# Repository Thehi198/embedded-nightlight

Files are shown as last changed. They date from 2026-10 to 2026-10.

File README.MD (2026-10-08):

# Nightlight: Event-Driven Ambient Light Controller on STM32F446RE

**Demo video:** [docs/demo.mp4](docs/demo.mp4) 

## Overview

This nightlight measures room darkness with a photoresistor and fades in red, yellow, and green LEDs in three stages as the room gets darker. It is fully event-driven on an STM32F446RE. A single interrupt callback converts each sampling window to photoresistor resistance, maps it to a normalized darkness value, and updates three 16-bit PWM channels, while the main loop sleeps on `__WFI()`. A DAC self-test verifies the ADC signal path using on board traces.

**Demo video:** [docs/demo.mp4](docs/demo.mp4) 

## Circuit

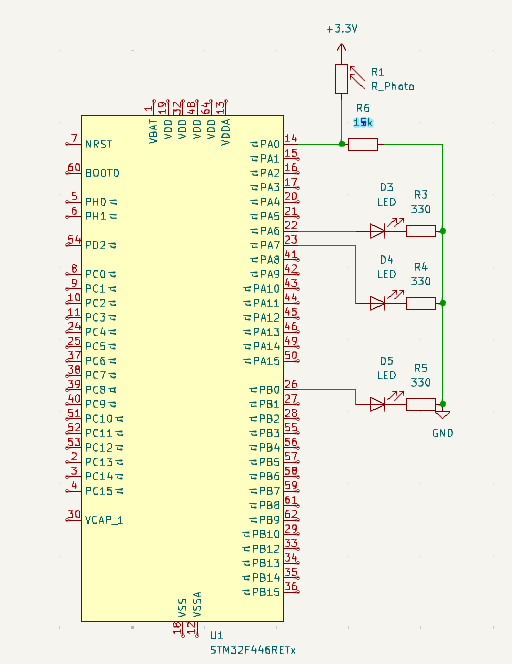
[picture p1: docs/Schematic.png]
Schematic


### Components

| Ref | Part | Value |
|:-|:-|:-|
| LDR1 | Photoresistor | Characterized below |
| R1 | Divider resistor | 15 kΩ |
| R2, R3, R4 | LED series resistors | 330 Ω |
| LED1 | Stage 1 LED | Red |
| LED2 | Stage 2 LED | Yellow |
| LED3 | Stage 3 LED | Green |

### Pin map

| Signal | MCU pin | Nucleo header | Function |
|:-|:-|:-|:-|
| Sensor | PA0 | A0 (CN8) | ADC1_IN0 |
| Self-test loopback | PA4 | A2 (CN8), unconnected | DAC_OUT1 / ADC1_IN4 |
| LED stage 1 | PA6 | D12 (CN5) | TIM3_CH1, AF2 |
| LED stage 2 | PA7 | D11 (CN5) | TIM3_CH2, AF2 |
| LED stage 3 | PB0 | A3 (CN8) | TIM3_CH3, AF2 |
| Sensor supply | 3V3 | CN6 | |
| Ground | GND | CN6 | |

### Divider design

ADC value rises with light.

$$c = 4096 \cdot \frac{R_{DIV}}{R_{LDR} + R_{DIV}}$$

For maximum voltage swing across the operating range, $R_{DIV} \approx \sqrt{R_{bright} R_{dark}}$.

## Sensor Characterization

### Method
LDR resistance was measured with a multimeter under different light sources of increasing brightness. 

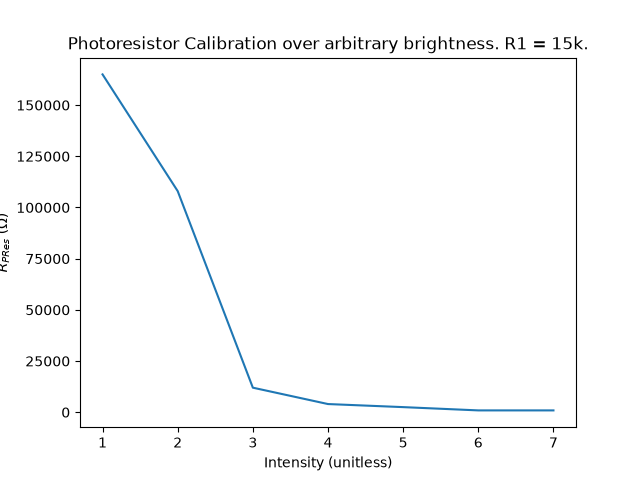
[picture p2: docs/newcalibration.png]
Resistance vs. intensity


The relationship is not linear. On log-log axes the data falls on a straight line, so the photoresistor follows a power law:

$$R = A \cdot L^{-\gamma}$$

Because $\ln R$ is linear in $\ln L$, and light intensity is roughly logarithmic, only the two calibration endpoints, max and min are needed

## System Architecture

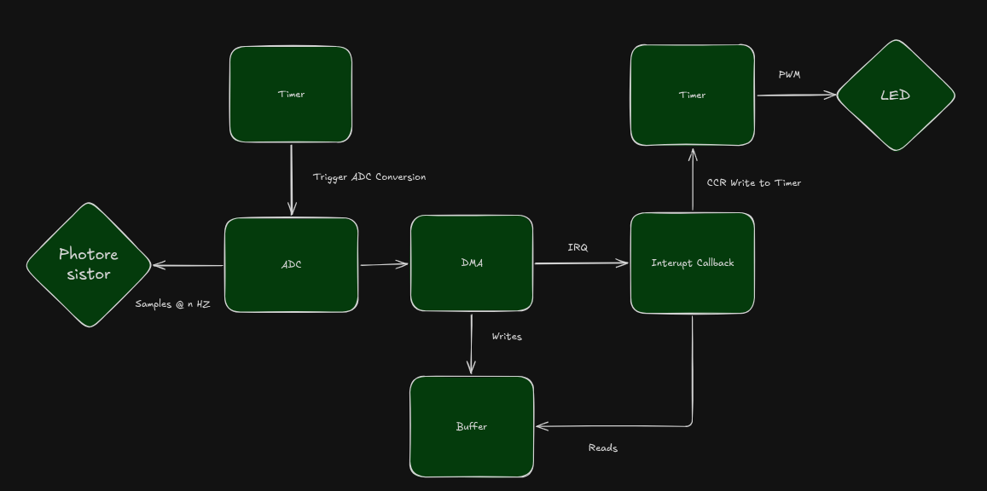
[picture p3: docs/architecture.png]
Architecture diagram


### Data flow

1. **TIM2** counts at 1 MHz effective and overflows every 833 µs. Each update event drives TRGO, which starts one ADC conversion in hardware.
2. **ADC1** converts PA0 with a 480-cycle sample time .
3. **DMA2 Stream 0** copies each result into a 120-entry circular buffer. 
4. When either half of the buffer fills, the DMA raises an interrupt and HAL calls the half-complete or complete callback.
5. **The callback** averages 60 samples, converts to resistance, maps to darkness, splits into three stages, and writes TIM3 CCR1 to CCR3.
6. **TIM3** generates three PWM waveforms continuously. 

### Brightness mapping

Average ADC sample output is converted to resistance:

$$R = R_{DIV}\ \frac{4096 - c}{c}$$

The resistance is converted to a "darkness" value to be normalized and processed by the stage function

$$d = \frac{\ln R - \ln R_{bright}}{\ln R_{dark} - \ln R_{bright}}$$

This value was clamped betwene 0 and 1

Darkness is converted to stage to stage $k = 0, 1, 2$:

$$s_k = (3d - k,\ 0,\ 1), \qquad \text{CCR}_{k+1} = 65535 \cdot s_k$$

Calibration: $R_{bright}$ = 2000 Ω, $R_{dark}$ = 8000 Ω.

## Design Decisions

| Constant | Value | Rationale |
|:-|:-|:-|
| System clock | 180 MHz from internal HSI | Maximum rated speed |
| ADC clock | 22.5 MHz  | Fastest sample setting |
| Sampling rate | 1200 Hz | 60 samples per 50 ms |
| ADC sample time | 480 cycles | Arbitrary |
| Buffer | 120 samples, two halves | 20 Hz update rate. CPU reads the half DMA, other half is being written to.|
| PWM frequency | 1373 Hz | Arbitrary |
| Filtering | 60-sample average only | Average sample reduces jitter in PWM|
| LED color order | Red, Yellow, Green | Based on what humans best see in different levels of light |

## Register Trace

Each CubeMX setting and the register field it writes. HAL source was used to find the fields

### ADC1

ADC1 converts the sensor on PA0 once per TIM2 trigger.

| CubeMX setting | Value | Register.field = value |
|:-|:-|:-|
| Clock Prescaler | PCLK2 / 4 | ADC_CCR.ADCPRE = 01 |
| Resolution | 12 bit | ADC_CR1.RES = 00 |
| Scan Conversion | Disabled | ADC_CR1.SCAN = 0 |
| Continuous Conversion | Disabled | ADC_CR2.CONT = 0 |
| Data Alignment | Right | ADC_CR2.ALIGN = 0 |
| DMA Continuous Requests | Enabled | ADC_CR2.DDS = 1 |
| DMA enable | (at start) | ADC_CR2.DMA = 1 |
| EOC Selection | Single conversion | ADC_CR2.EOCS = 1 |
| External Trigger | TIM2 TRGO | ADC_CR2.EXTSEL = 0110 |
| Trigger Edge | Rising | ADC_CR2.EXTEN = 01 |
| Number of Conversions | 1 | ADC_SQR1.L = 0000 |
| Rank 1 Channel | 0 | ADC_SQR3.SQ1 = 0 |
| Rank 1 Sample Time | 480 cycles | ADC_SMPR2.SMP0 = 111 |
| Self-test channel | 4 (flag only) | ADC_SQR3.SQ1 = 4, ADC_SMPR2.SMP4 = 111 |

### DMA2 Stream 0

DMA2 Stream 0 moves every ADC result into a 120-sample circular buffer and interrupts at each half.

| CubeMX setting | Value | Register.field = value |
|:-|:-|:-|
| Request | ADC1 | DMA_S0CR.CHSEL = 000 |
| Direction | Peripheral to memory | DMA_S0CR.DIR = 00 |
| Mode | Circular | DMA_S0CR.CIRC = 1 |
| Memory increment | On | DMA_S0CR.MINC = 1 |
| Peripheral increment | Off | DMA_S0CR.PINC = 0 |
| Data width | Half word | DMA_S0CR.PSIZE = 01, MSIZE = 01 |
| Priority | High | DMA_S0CR.PL = 10 |
| FIFO | Off | DMA_S0FCR.DMDIS = 0 |
| Length | 120 (at start) | DMA_S0NDTR = 120 |

### TIM2 (ADC trigger)

TIM2 paces the ADC at 1.2 kHz:

| CubeMX setting | Value | Register.field = value |
|:-|:-|:-|
| Prescaler | 74 | TIM2_PSC = 74 |
| Counter Period | 999 | TIM2_ARR = 999 |
| Counter Mode | Up | TIM2_CR1.DIR = 0 |
| Auto-reload preload | Enable | TIM2_CR1.ARPE = 1 |
| Trigger Event (TRGO) | Update | TIM2_CR2.MMS = 010 |

### TIM3 (LED PWM)

TIM3 drives the three LEDs with 1373 Hz, 16-bit PWM.

| CubeMX setting | Value | Register.field = value |
|:-|:-|:-|
| Prescaler | 0 | TIM3_PSC = 0 |
| Counter Period | 65535 | TIM3_ARR = 0xFFFF |
| Auto-reload preload | Enable | TIM3_CR1.ARPE = 1 |
| PWM Mode | PWM mode 1 | TIM3_CCMR1.OC1M/OC2M = 110, TIM3_CCMR2.OC3M = 110 |
| Output compare preload | Enable | OC1PE/OC2PE/OC3PE = 1 |
| Polarity | High | TIM3_CCER.CCxP = 0 |
| Output enable | (at start) | TIM3_CCER.CCxE = 1 |
| Pins | AF2 | GPIOA_AFRL.AFRL6/7 = 0010, GPIOB_AFRL.AFRL0 = 0010 |

### DAC (self-test)

The DAC drives known voltages onto PA4 for the loopback self-test and is only used when `ENABLE_DAC_SELFTEST` is 1.

| CubeMX setting | Value | Register.field = value |
|:-|:-|:-|
| Output buffer | Enable | DAC_CR.BOFF1 = 0 |
| Trigger | None | DAC_CR.TEN1 = 0 |
| Enable | (at start) | DAC_CR.EN1 = 1 |
| Data | per step | DAC_DHR12R1 |

## Testing

### DAC self-test

With `ENABLE_DAC_SELFTEST = 1`, ADC1 reads channel 4 (PA4). Each DMA callback averages 60 samples of the code written by the previous callback, compares, and writes the next code. Because the DAC and ADC share VREF+, the expected ADC code equals the DAC code.

 With the output buffer enabled, the DAC only swings from 0.2 V to $V_{DDA} - 0.2$ V (datasheet Table 85), about codes 248 to 3848, so codes near the rails are excluded.

**Tolerance.**:

| Source | Spec | LSB |
|:-|:-|:-|
| DAC offset | ±10 mV (Table 85) | ±12.4 |
| DAC gain | ±0.5% (Table 85) | ±0.005 × code |
| DAC INL | ±4 LSB (Table 85) | ±4 |
| ADC total unadjusted error | ±5 LSB (Table 76) | ±5 |

$$\text{tol}(n) = \lceil 21.4 + 0.005\,n \rceil\ \text{LSB}$$

**Results.**

| DAC code | ADC measured | Error (LSB) | Tolerance (LSB) | Pass |
|:-|:-|:-|:-|:-|
| 300 | 281 | -19 | 23 | ✓ |
| 750 | 738 | -12 | 26 | ✓ |
| 1200 | 1194 | -6 | 28 | ✓ |
| 1650 | 1654 | 4 | 30 | ✓ |
| 2100 | 2111 | 11 | 32 | ✓ |
| 2550 | 2568 | 18 | 35 | ✓ |
| 3000 | 3024 | 24 | 37 | ✓ |
| 3450 | 3479 | 29 | 39 | ✓ |
| 3800 | 3835 | 35 | 41 | ✓ |

## Obstacles

The first run of the DAC  self-test failed. The DAC stepped from 300 to 3800, but the ADC read about 1699 counts for all nine steps. Since the reading did not  not move at all while the input sweeps the full range it meant that the the ADC was not looking at the DAC. 1699 counts corresponds to about 21 kΩ on the 15 kΩ divider, a normal room-light value for the photoresistor, so the ADC was most likely still sampling PA0 instead of PA4. Covering the sensor shifted the "measured" values, which confirmed it. In the STM32CubeIDE SFR view, ADC1_SQR3.SQ1 read 0 instead of 4.

The code that switches rank 1 to channel 4 was in `USER CODE BEGIN ADC1_Init 1`. That block runs before `HAL_ADC_Init` and before CubeMX's generated channel 0 configuration, so the generated code silently overwrote my setting every boot. 

In a CubeMX project, which USER CODE block a line goes in decides when it runs relative to the generated initialization. The source looked correct; only reading the register showed what the hardware was actually configured to do.

## Build and Run

1. Open the project in STM32CubeIDE.
2. In `main.c`, set `ENABLE_DAC_SELFTEST` to `0` for normal operation or `1` for the self-test.
3. Set `R_BRIGHT_OHMS` and `R_DARK_OHMS` to your calibration values.
4. Build and flash. With the self-test enabled, inspect `st_results` and `st_pass` in Live Expressions.

## Repository Structure

```
.
├── Core/              CubeMX-generated sources; application code in main.c USER CODE blocks
├── Drivers/           HAL and CMSIS
├── docs/              Photos, schematic, plots, architecture diagram, demo video
├── characterization/  TODO: raw data and plotting script
├── nightlight.ioc     CubeMX configuration
└── README.md
```

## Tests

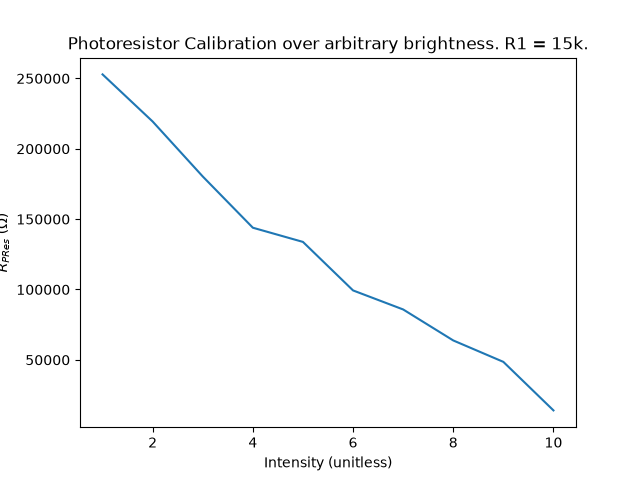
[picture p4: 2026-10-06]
calibration/newcalibration.png

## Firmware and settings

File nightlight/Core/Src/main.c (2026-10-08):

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
/* Includes ------------------------------------------------------------------*/
#include "main.h"

/* USER CODE BEGIN Includes */
#include <math.h>
/* USER CODE END Includes */

/* USER CODE BEGIN PD */
#define ADC_BUFFER_LEN   120U
#define HALF_LEN      (ADC_BUFFER_LEN / 2U)
#define R_DIV_OHMS    15000.0f
#define R_BRIGHT_OHMS   2000.0f
#define R_DARK_OHMS     80000.0f
#define PWM_MAX         65535.0f
#define ENABLE_DAC_SELFTEST  1
#define ST_N                 9U
/* USER CODE END PD */

ADC_HandleTypeDef hadc1;
DMA_HandleTypeDef hdma_adc1;

DAC_HandleTypeDef hdac;

TIM_HandleTypeDef htim2;
TIM_HandleTypeDef htim3;

/* USER CODE BEGIN PV */
static uint16_t adc_buffer[ADC_BUFFER_LEN];
volatile uint16_t adc_avg     = 0;
volatile float    pr_ohms    = 0.0f;
volatile uint32_t adc_updates = 0;
static float ln_r_bright;
static float ln_r_span;
volatile float darkness = 0.0f;



#if ENABLE_DAC_SELFTEST
typedef struct {
    uint16_t code;
    uint16_t measured;
    int16_t  error;
    uint16_t tol;
    uint8_t  pass;
} st_result_t;

static const uint16_t codes[ST_N] = {300, 750, 1200, 1650, 2100, 2550, 3000, 3450, 3800};
volatile st_result_t ST_results[ST_N];
volatile int8_t st_pass = -1;
static uint32_t st_idx = 0;
static uint8_t  st_pending = 0;
#endif

/* USER CODE END PV */

void SystemClock_Config(void);
static void MX_GPIO_Init(void);
static void MX_DMA_Init(void);
static void MX_ADC1_Init(void);
static void MX_DAC_Init(void);
static void MX_TIM2_Init(void);
static void MX_TIM3_Init(void);
/* USER CODE BEGIN 0 */
#if ENABLE_DAC_SELFTEST
/* Worst-case DAC offset + gain + INL plus ADC TUE, rounded up:
   tol = ceil(21.4 + 0.005 * n) LSB */
static uint16_t st_tolerance(uint16_t n)
{
    return (uint16_t)((21400U + 5U * n + 999U) / 1000U);
}

static void selftest_step(uint16_t measured)
{
    if (st_pending) {
        uint16_t code = codes[st_idx];
        int16_t  err  = (int16_t)((int32_t)measured - (int32_t)code);
        uint16_t tol  = st_tolerance(code);

        ST_results[st_idx].code     = code;
        ST_results[st_idx].measured = measured;
        ST_results[st_idx].error    = err;
        ST_results[st_idx].tol      = tol;
        ST_results[st_idx].pass     = (uint8_t)((err < 0 ? -err : err) <= (int16_t)tol);

        st_idx++;
        st_pending = 0;
    }

    if (st_idx < ST_N) {
        HAL_DAC_SetValue(&hdac, DAC_CHANNEL_1, DAC_ALIGN_12B_R, codes[st_idx]);
        st_pending = 1;
    } else if (st_pass < 0) {
        uint8_t all = 1;
        for (uint32_t i = 0; i < ST_N; i++) all &= st_results[i].pass;
        st_pass = (int8_t)all;
    }
}
#endif

static float stage(float d, int k) /*Select led stage*/
{
    float s = 3.0f * d - (float)k;
    if (s < 0.0f) s = 0.0f;
    if (s > 1.0f) s = 1.0f;
    return s;
}

static void process_half(const uint16_t *src)
{
    uint32_t sum = 0;
    for (uint32_t i = 0; i < HALF_LEN; i++) {
        sum += src[i];
    }
    uint32_t c = (sum + HALF_LEN / 2U) / HALF_LEN;
    if (c < 1U)    c = 1U;
    if (c > 4095U) c = 4095U; /*Keep R finite and positive or else the log blows up*/

	#if ENABLE_DAC_SELFTEST
		selftest_step((uint16_t)c);
		return;
	#endif

    adc_avg = (uint16_t)c; /*view in debug*/
    pr_ohms = R_DIV_OHMS * (float)(4096U - c) / (float)c; /*calculate ohms of pr*/

    float d = (logf(pr_ohms) - ln_r_bright) / ln_r_span; /*calculate normalized brightness*/
    if (d < 0.0f) d = 0.0f;
    if (d > 1.0f) d = 1.0f;
    darkness = d; /*view in debug*/

    __HAL_TIM_SET_COMPARE(&htim3, TIM_CHANNEL_1, (uint32_t)(stage(d, 0) * PWM_MAX + 0.5f));
    __HAL_TIM_SET_COMPARE(&htim3, TIM_CHANNEL_2, (uint32_t)(stage(d, 1) * PWM_MAX + 0.5f));
    __HAL_TIM_SET_COMPARE(&htim3, TIM_CHANNEL_3, (uint32_t)(stage(d, 2) * PWM_MAX + 0.5f));
}

void HAL_ADC_ConvHalfCpltCallback(ADC_HandleTypeDef *hadc)
{
    if (hadc->Instance == ADC1) process_half(&adc_buffer[0]);
}

void HAL_ADC_ConvCpltCallback(ADC_HandleTypeDef *hadc)
{
    if (hadc->Instance == ADC1) process_half(&adc_buffer[HALF_LEN]);
}

/* USER CODE END 0 */

/**
  * @brief  The application entry point.
  * @retval int
  */
int main(void)
{

  /* MCU Configuration--------------------------------------------------------*/

  /* Reset of all peripherals, Initializes the Flash interface and the Systick. */
  HAL_Init();

  /* Configure the system clock */
  SystemClock_Config();

  /* Initialize all configured peripherals */
  MX_GPIO_Init();
  MX_DMA_Init();
  MX_ADC1_Init();
  MX_DAC_Init();
  MX_TIM2_Init();
  MX_TIM3_Init();
  /* USER CODE BEGIN 2 */
  ln_r_bright = logf(R_BRIGHT_OHMS);
  ln_r_span   = logf(R_DARK_OHMS) - ln_r_bright;

  HAL_DBGMCU_EnableDBGSleepMode();

  HAL_TIM_PWM_Start(&htim3, TIM_CHANNEL_1);
  HAL_TIM_PWM_Start(&htim3, TIM_CHANNEL_2);
  HAL_TIM_PWM_Start(&htim3, TIM_CHANNEL_3);

#if ENABLE_DAC_SELFTEST
  if (HAL_DAC_Start(&hdac, DAC_CHANNEL_1) != HAL_OK) {
      Error_Handler();
  }
#endif

  if (HAL_ADC_Start_DMA(&hadc1, (uint32_t *)adc_buffer, ADC_BUFFER_LEN) != HAL_OK) {
      Error_Handler();
  }
  if (HAL_TIM_Base_Start(&htim2) != HAL_OK) {
      Error_Handler();
  }

  /* USER CODE END 2 */

  /* Infinite loop */
  /* USER CODE BEGIN WHILE */
  while (1)
  {
    /* USER CODE END WHILE */

    /* USER CODE BEGIN 3 */
	  __WFI();
  }
  /* USER CODE END 3 */
}

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


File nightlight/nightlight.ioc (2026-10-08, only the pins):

Mcu.UserName=STM32F446RETx
PA0-WKUP.Signal=ADCx_IN0
PA13.Signal=SYS_JTMS-SWDIO
PA14.Signal=SYS_JTCK-SWCLK
PA4.Signal=COMP_DAC1_group
PA6.Signal=S_TIM3_CH1
PA7.Signal=S_TIM3_CH2
PB0.Signal=S_TIM3_CH3
PH0-OSC_IN.Signal=RCC_OSC_IN
PH1-OSC_OUT.Signal=RCC_OSC_OUT

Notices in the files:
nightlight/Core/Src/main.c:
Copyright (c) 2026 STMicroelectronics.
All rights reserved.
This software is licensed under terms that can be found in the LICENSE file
